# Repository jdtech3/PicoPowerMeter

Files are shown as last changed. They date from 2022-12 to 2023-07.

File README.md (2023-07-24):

# PicoPowerMeter

## ?¿

Voltage/current/power/energy meter using the Raspberry Pi Pico, aiming to be ± 0.1% @ 0-24V and 0-1A

## Pics

<pre>
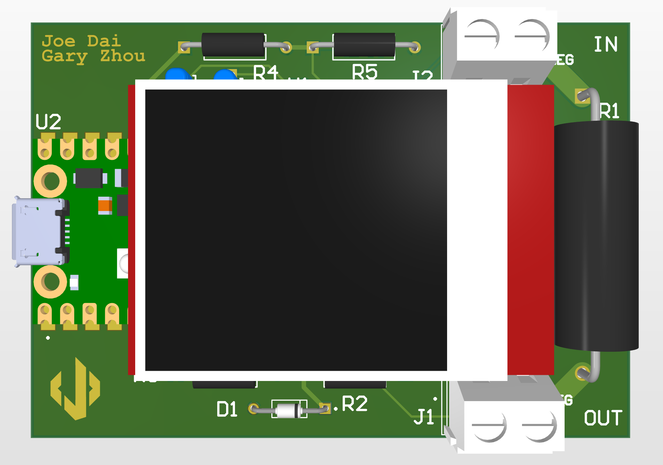
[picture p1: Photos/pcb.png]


                        ↓↓↓

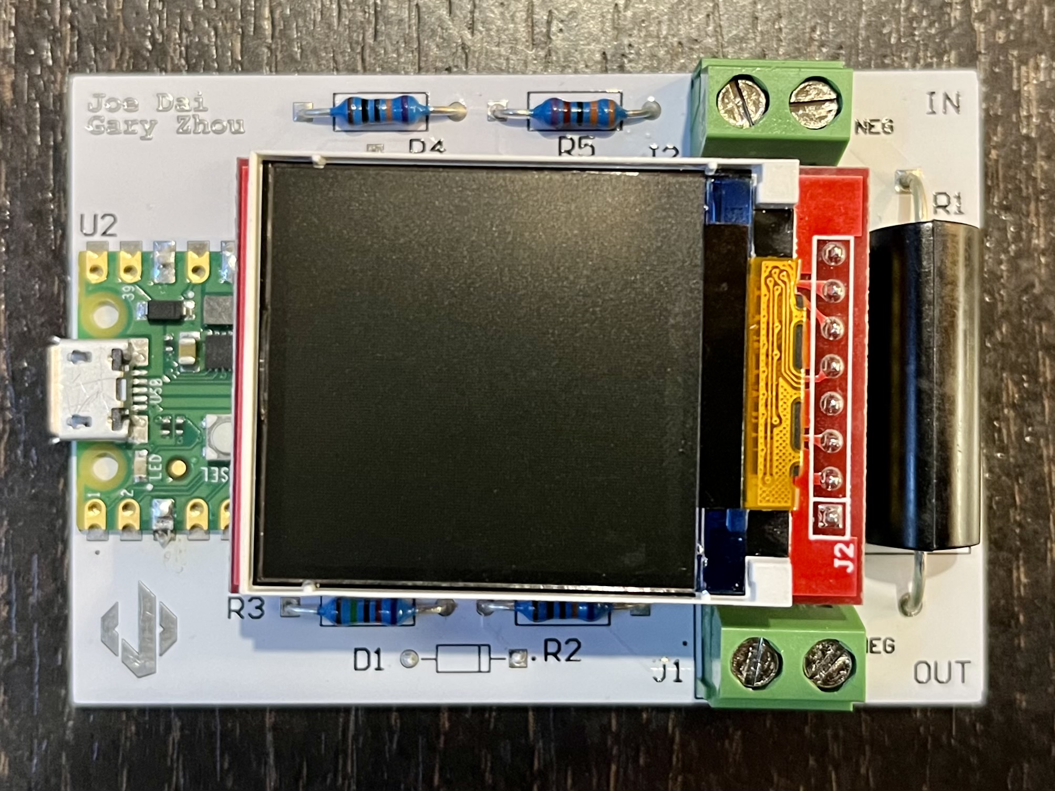
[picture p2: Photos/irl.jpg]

</pre>

## Calibration

Even when oversampling by averaging over 10,000 samples, we noticed that there were significant errors (up to ± 10%) with the voltage measurements:



This seems to be due to the poor DNL and INL (differential and integral non-linearity respectively) of the Raspberry Pi Pico ADC, as our measured "jumps" correspond almost exactly to the Pico's DNL spikes as measured by [Mark Omo's excellent characterization of the Pico's ADC](https://pico-adc.markomo.me/INL-DNL/).

Methodology and raw calibration data for our Pico is available [here](https://docs.google.com/spreadsheets/d/1IjrpbZwi6U-m_iKFwJcBlV5J3Jlb0WuwdMCl5kuGMQ8/edit?usp=sharing).

_**TODO:** Final accuracy and repeatability specs are pending a better automation calibration script being completed._

## Contributors

* [Joe Dai](https://github.com/jdtech3)
* [Gary Zhou](https://github.com/GaryZhous/)

---

*This project is licensed under NONE, TBD. For more information, please see TBD.*

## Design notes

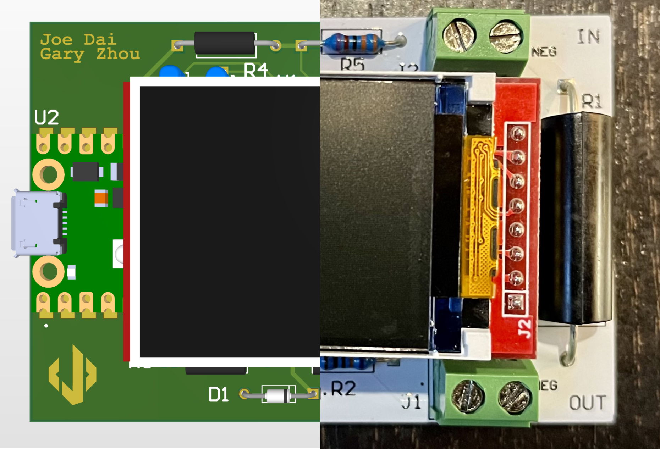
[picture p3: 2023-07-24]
Photos/combined.jpg

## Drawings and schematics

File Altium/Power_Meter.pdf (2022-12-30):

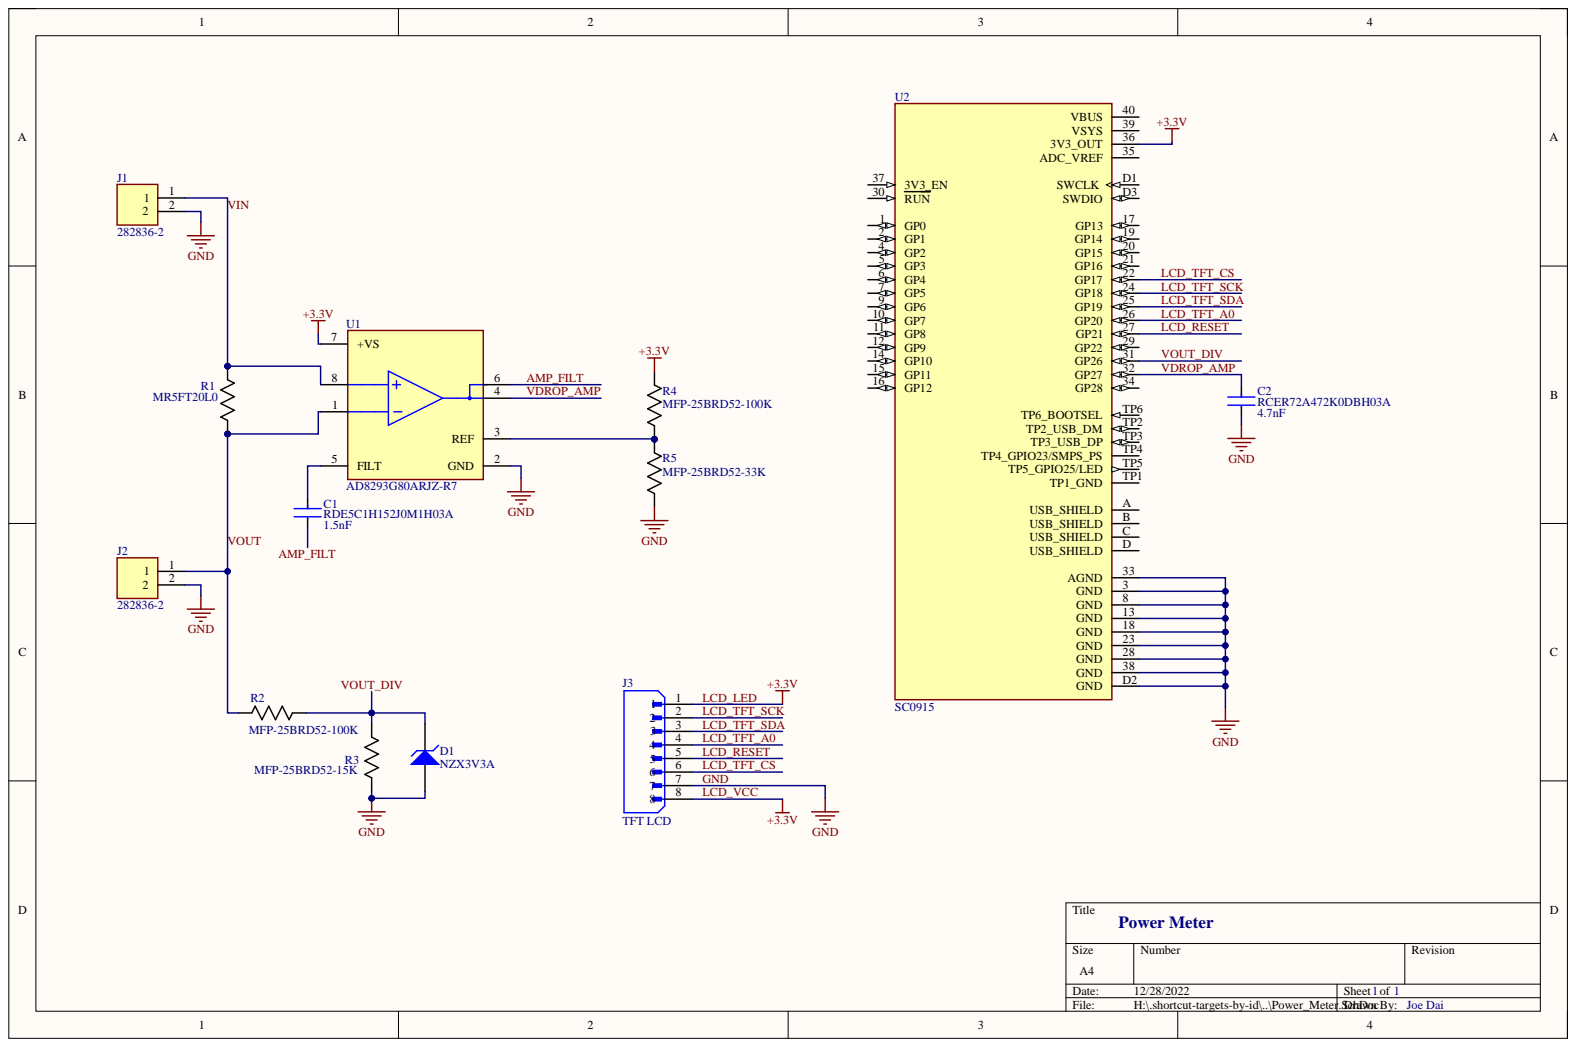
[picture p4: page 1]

Size A 4 | Numbe r | Revision

Date: 12/28/2022 | Sheet of 1 1
File: H:\.shortcut-targets-by-id\..\Power_Meter | . SDrawn chDocBy: Joe Dai

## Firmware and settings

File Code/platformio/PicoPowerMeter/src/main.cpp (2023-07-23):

#include <Arduino.h>    // Arduino core
#include "SPI.h"        // LCD
#include "pico/time.h"  // for time span measurement
#include <TFT_eSPI.h>

extern "C" {                  // Reboot into USB mode
  #include "pico/bootrom.h"   // C linkage guard required per https://forums.raspberrypi.com/viewtopic.php?t=302963
}

#include "utils.h"      // Bootsel detection
#include "settings.h"   // Settings

#define PS_PIN      23  // Pico power supply mode pin

#define TEXT_START_COL_OFFSET   3   // TFT text settings
#define TEXT_START_ROW_OFFSET   3
#define TEXT_ROW_SPACING        15
#define TEXT_FONT_SIZE          1

// #define VOUT_CONVERSION(x) ((( x * (3.295 / 4096.0) / 0.130383) - 0.22) * 1.048365)
#define VOUT_CONVERSION(x) ( x * (3.3 / 4096.0) / 0.130383)
#define ADC_correction (3.295/4096.0)

TFT_eSPI tft = TFT_eSPI();

double voltage;
double current;
double power;
absolute_time_t last_measurement_time;  // time stamp
double temporary_pow = 0.0;             // temporarily store a power value
double energy;

void reset_measurements() {
  voltage = 0.0;
  current = 0.0;
  energy = 0.0;
  power = 0.0;
}

// Calibration of voltage
double get_calibrated_voltage(double v){
  if (v <= 3.048) {
    return v + 0.05013386496*(v) + (-0.231968332926672);
  }
  else if (v <= 9.356) {
    return v + 0.03801254021*(v) + (-0.1511130402);
  }
  else if (v <= 15.658) {
    return v + 0.03641967881*(v) + (-0.07988468282);
  }
  else if (v <= 22.047) {
    return v + 0.0387455535*(v) + (-0.05433042421);
  }
  else{
    return v + 0.03681099704*(v) + (0.05546201889);
  }
}

void println_to_tft(char* str, double val) {
  // Set cursor and clear
  tft.setCursor(TEXT_START_COL_OFFSET, TEXT_START_ROW_OFFSET + tft.getCursorY() + TEXT_ROW_SPACING);
  tft.print("                ");
  tft.setCursor(TEXT_START_COL_OFFSET, tft.getCursorY());

  // Format and print
  char buf[16];
  sprintf(buf, str, val);
  tft.print(buf);
}

void setup() {
  // Pins
  pinMode(PIN_LED, OUTPUT);
  pinMode(PIN_VOUTDIV, INPUT);
  pinMode(PIN_VDROPAMP, INPUT);
  pinMode(PIN_GNDREF, INPUT);

  Serial.begin(9600);   // initialize serial communication

  // TFT
  tft.init();
  tft.setRotation(1);
  tft.setTextSize(TEXT_FONT_SIZE);
  tft.fillScreen(TFT_BLACK);

  // Measurements
  analogReadResolution(12);
  digitalWrite(PS_PIN, HIGH);
  reset_measurements();
  last_measurement_time = get_absolute_time();  // the very first time stamp
}

void loop() {
  // BOOTSEL button detection
  if (get_bootsel_button()) {
    digitalWrite(PIN_LED, HIGH);

    #ifdef BOOTSEL_BUTTON_MODE_BOOTSEL
      reset_usb_boot(0, 0);
    #elif BOOTSEL_BUTTON_MODE_CLEAR_MEASUREMENTS
      reset_measurements();
    #endif
  }

  tft.setCursor(0, -TEXT_ROW_SPACING);  // reset cursor

  // Get and display Vout (calibrated)
  double sum = 0.0;
  for (int i = 0; i < NUM_OF_MEASUREMENTS; i++) {
    sum += (analogRead(PIN_VOUTDIV) - analogRead(PIN_GNDREF));
    delay(MEASUREMENT_DELAY);
  }
  sum /= NUM_OF_MEASUREMENTS;

  voltage = get_calibrated_voltage(VOUT_CONVERSION(sum));
  println_to_tft("V: %.3f V", voltage);

  digitalWrite(PIN_LED, (voltage > 24.0) ? HIGH : LOW);   // overvoltage warning


  // Get and display I (calibrated)
  for (;;) {
    current = analogRead(PIN_VDROPAMP)*ADC_correction / 80 / 0.02;
    delay(0.1);
    double test = analogRead(PIN_VDROPAMP)*ADC_correction / 80 / 0.02;
    if (abs((current - test) / current) < 0.001) break;
  }

  // Display I
  println_to_tft("I: %.3f A", current);

  // Calculate and display P
  power = current * voltage;
  absolute_time_t new_time = get_absolute_time(); // new timestamp
  println_to_tft("P: %.3f W", power);

  // Calculate and display E
  energy += (power+temporary_pow)*absolute_time_diff_us(last_measurement_time, new_time)/(2*1000000);
  println_to_tft("E: %.3f J", energy);
  temporary_pow = power;
  last_measurement_time = new_time;   // pass on the time stamp

  delay(10);  // slow down loop
}

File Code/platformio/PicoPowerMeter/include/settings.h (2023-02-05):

#ifndef SETTINGS_H
#define SETTINGS_H

// --- Choose one ---
#define BOOTSEL_BUTTON_MODE_BOOTSEL
// #define BOOTSEL_BUTTON_MODE_CLEAR_MEASUREMENTS

// --- Pins ---
#define PIN_VOUTDIV             26
#define PIN_VDROPAMP            27
#define PIN_GNDREF              28

// --- Number/speed of measurements to average ---
#define NUM_OF_MEASUREMENTS     10000    // ~1000 is best
#define MEASUREMENT_DELAY       0.05     // in ms

#endif

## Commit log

2022-12-30 Initial commit - v1 schematic + PCB done
    [282836-2.PcbLib, 282836-2.SchLib, G800LE300018YEU.PcbLib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]
2022-12-31 Reorganized files
    [282836-2.PcbLib, 282836-2.SchLib, G800LE300018YEU.PcbLib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]
2023-01-01 Include libraries + reroute some traces
    [Power_Meter.PcbDoc, Power_Meter.SchDoc]
2023-01-05 Re-add libraries to PrjPcb
    [Power_Meter.PrjPcb]
2023-01-06 Experimental voltage measurement code
2023-01-06 updated the rest of the codes for further test
    current, led, energy
2023-01-06 Allow USB boot and reset measurements thru BOOTSEL button; add settings.h; general cleanup
    [main.cpp, settings.h, utils.cpp]
2023-01-06 removed broken library and pointers
    [arduino.ino]
2023-01-08 change the unit of power
2023-01-08 Pico footprint - added solder mask expansion
    [Power_Meter.PcbDoc]
2023-01-10 Add current sense resistor value to VDROP
2023-01-10 added calibration method for Vout
2023-01-11 Increase sample rate + add calibration curves for voltage
2023-01-11 Update README.md - add calibration section
2023-01-11 corrected the calibration mechanism
    [arduino.ino]
2023-02-05 Move current sense to low side + fix DRC
    [Power_Meter.PcbDoc, Power_Meter.SchDoc]
2023-02-05 Add logos and info to PCB
    [Power_Meter.PcbDoc]
2023-02-07 Load and check against JLCPCB DRC
    [Power_Meter.PcbDoc, Power_Meter.PrjPcb]
2023-02-07 Generate gerbers
    [Power_Meter.GBL, Power_Meter.GBO, Power_Meter.GBP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]
2023-02-08 Correct VDROP_AMP filter cap, add In-Amp power bypass cap
    [Power_Meter.PcbDoc, Power_Meter.SchDoc]
2023-02-11 Add bypass cap on in-amp REF + misc changes
    [Power_Meter.GBL, Power_Meter.GBO, Power_Meter.GBP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]
2023-02-21 Add calibration dir
2023-02-21 updated calibration curve
2023-06-14 Fix NZX3V3A 3D model
    [Power_Meter.PcbDoc]
2023-07-23 Deprecate Arduino code
